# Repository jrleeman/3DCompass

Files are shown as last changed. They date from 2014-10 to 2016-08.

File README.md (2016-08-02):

# 3D Compass

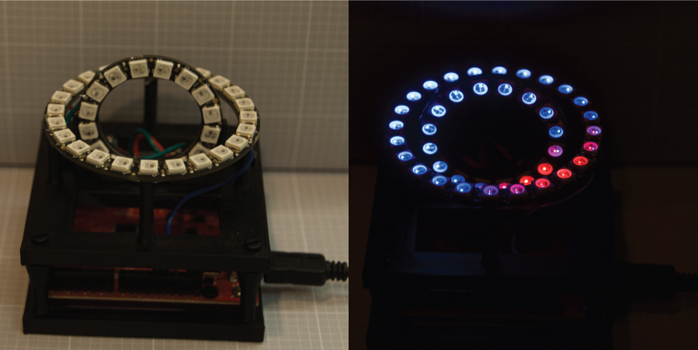
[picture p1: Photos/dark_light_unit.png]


## Bill of Materials
- (1) [Arduino UNO (I used a Red board from SparkFun)](https://www.sparkfun.com/products/12757) $19.95/ea
- (1) [NeoPixel Ring - 16 Element](http://www.adafruit.com/products/1463) $9.95/ea
- (1) [NeoPixil Ring - 24 Element](http://www.adafruit.com/products/1586) $19.95/ea
- (1) [1000uF Capacitor - 6.3V or higher](https://www.sparkfun.com/products/8982) $0.35/ea
- (1) [HMC5883L Magnetometer](http://www.adafruit.com/products/1746) $9.95/ea
- (10) [Brass Heat-Set Insert 4-40](http://www.mcmaster.com/#93365a122/=ub3kod) $11.48/pk. 100
- 0.1" Header Pins
- Hook-up wire (solid)
- 300-500 Ohm Resistor (1/8 watt)
- Nylon 4-40 Screws (1/2 - 1" length)

## Tools Required
- Hobby Knife
- Drill
- Drill Bit 7/64"
- Soldering Iron/Solder
- Flat-head screwdriver
- Hot Glue Gun/Glue
- USB mini cable

## Mechanical Assembly Instructions

### 3D Printing Brackets
- Print 1 top and 1 bottom bracket. 60% infill and a raft are recommended.
- Using a soldering iron, insert the heat-set thread inserts. Eight in
bottom plate, 4 in riser posts, 4 in Arduino mounts. Two in top plate for
magnetometer mounts. [Demonstration Video](http://youtu.be/NXAhOEn8nXQ)

### Assemble Top Plate
- Attach the magnetometer with 4-40 nylon screws. Shear the excess length flush
with the bottom of the plate using a hobby knife. Be careful to not break
the superstructure on the printed part.
- Place the capacitor into the cut-out and secure with a drop of hot glue.
- Solder ~5 cm of wire onto the data in line on the 16-element ring.
- Place the 16-element NeoPixel ring into the vertical ring holder. Thread the
data-in line through the hole in the bracket. This ensures that data-in, V+,
and GND are all accessable. Secure with a drop of hot-glue.
- Place the 24-element NeoPixel ring onto the riser posts. Line up the data-out
pad to be near the data-in line on the smaller ring. The LED should be directly
above the mounting post. Secure with hot-glue on each post.

### Assemble Bottom Plate
- Secure the Arduino RedBoard to the base plate with 4-40 nylon screws. Shear
the excess length flush with the bottom of the plate using a hobby knife.

### Attaching the Plates
- Using the 4-40 nylon screws, attach the top and bottom plates. Shear
the excess length flush with the bottom of the plate using a hobby knife. You
may prefer to do the wiring with the screws out for easy access, but it
shouldn't be too much of a problem.

## Wiring Instructions
* See photos on how to make this easier with header.
- Trim and solder the data-in wire on the vertical ring to the data-out pad
on the 24-element ring.
- Connect the data-in pad on the 24-element horizontal ring to pin 13 on the
Arduino. The resistor goes in-line here as well. You can use 0.1" header to make this easier to assemble and troubleshoot.
- Connect a ground pad from the 24-element horizontal ring to a ground pad
on the 16-element vertical ring.
- Connect the second ground pad on the 16-element vertical ring to the ground
size of the capacitor (marked with -- on the case).
- Connect the ground side of the capacitor to GND on the Arduino. Header can
make this easier.
- Connect the power pads of both rings to the positive side of the capacitor.
- Connect the positive side of the capacitor to +5VDC on the Arduino.
- Connect the GND, SDA, and SCL pins of the magnetometer to GND, SDA, and SCL
on the Arduino.
- Connect the power pin of the magnetometer to the +3.3VDC pin on the Arduino.

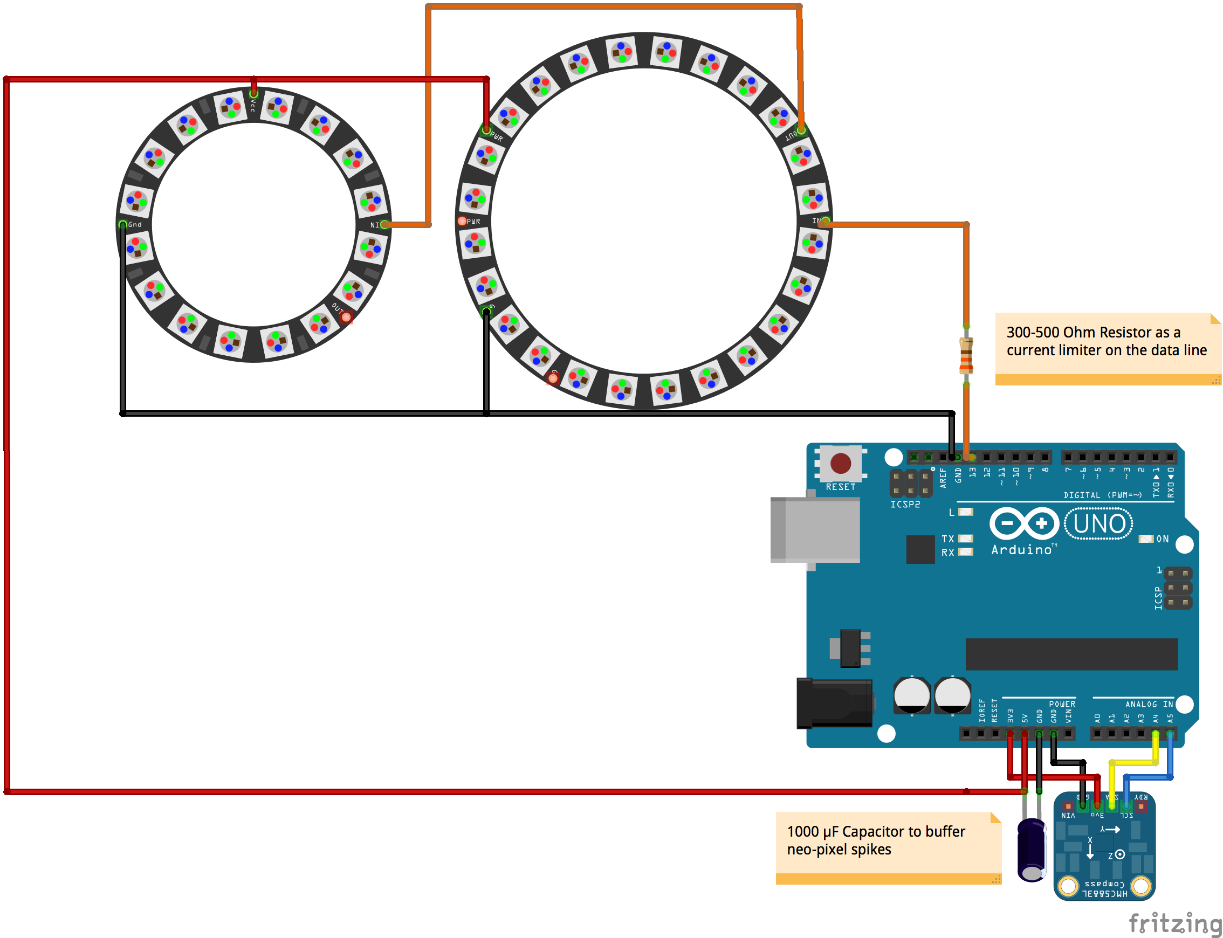
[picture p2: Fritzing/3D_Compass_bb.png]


## Programming
- Install the [NeoPixel](https://github.com/adafruit/Adafruit_NeoPixel),
[Adafruit Sensor](https://github.com/adafruit/Adafruit_Sensor), and
[Magnetometer](https://github.com/adafruit/Adafruit_HMC5883_Unified) libraries.
For help, see the [library tutorial.](https://learn.adafruit.com/adafruit-all-about-arduino-libraries-install-use)
- Connect the Arduino to your computer and upload the code in the Arduino/Vector_Display directory (see the [Arduino guide](http://arduino.cc/en/Guide/HomePage)) if you need help uploading programs to the Arduino.
- Play with parameters such as brightness and grading to create your own display!
- The `#define DECLINATION` directive adjusts the compass headings for your current location.  You can look up this value on the [CIRES World Magnetic Map](http://geomag.org/models/wmm-declination.html), but you need to convert the DMS to radians.

## Activity Ideas
You can learn a lot from your new compass/magnetometer! In addition to learning about the
electronics and hardware, you can learn about magnetic fields and the Earth's geodynamo. Below are a few links to get you started and some ideas. Please contribute any experiments or activities that you develop!

- Learn how magnetometer calibration works ([Freescale App Note](http://www.freescale.com/files/sensors/doc/app_note/AN4246.pdf))
- Measure the diurnal variation in [Earth's magnetic field](http://geophysics.ou.edu/solid_earth/notes/mag_earth/earth.htm)
- See how good of a [metal detector](http://en.wikipedia.org/wiki/Metal_detector) you built
- Detect the movement of metal objects like a desk drawer

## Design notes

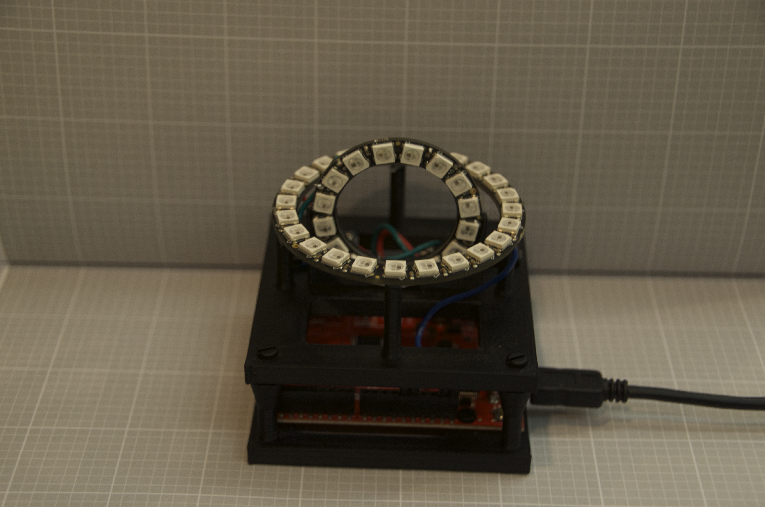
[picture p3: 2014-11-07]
Photos/unit_overview_2.jpg

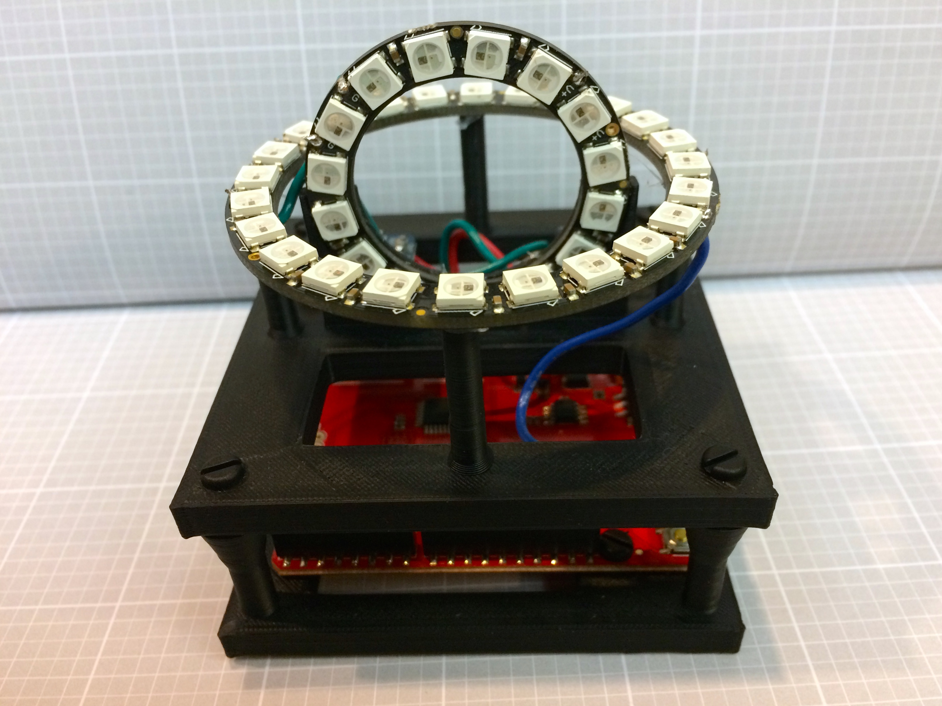
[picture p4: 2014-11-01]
Photos/unit_overview.jpg

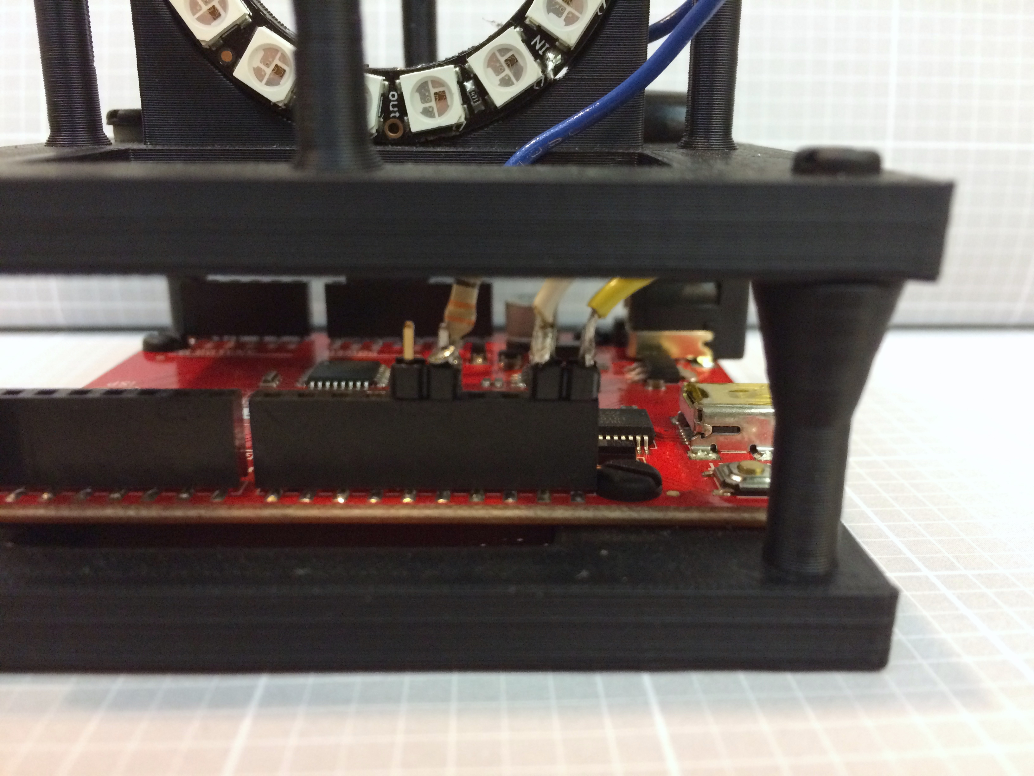
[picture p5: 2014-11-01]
Photos/side_b_detail.jpg

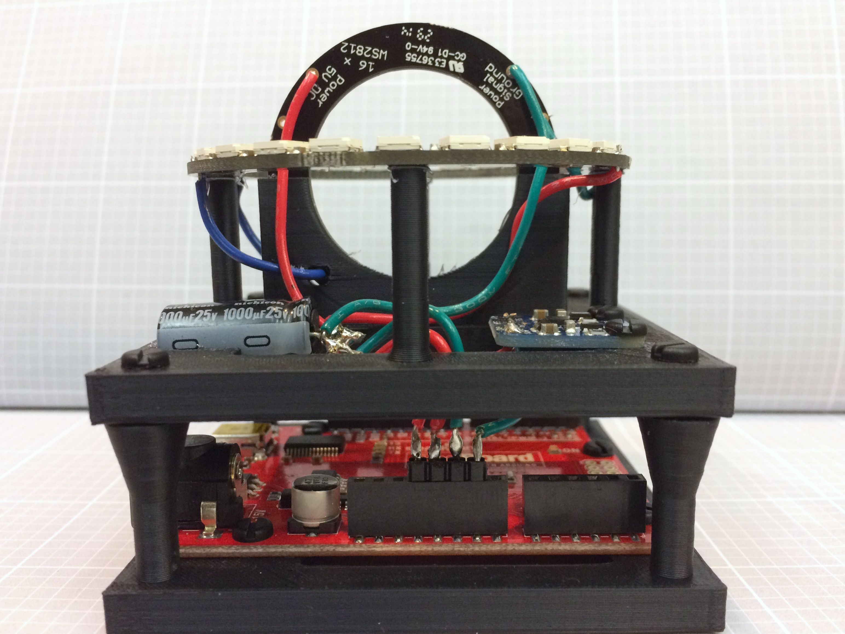
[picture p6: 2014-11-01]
Photos/side_a.jpg

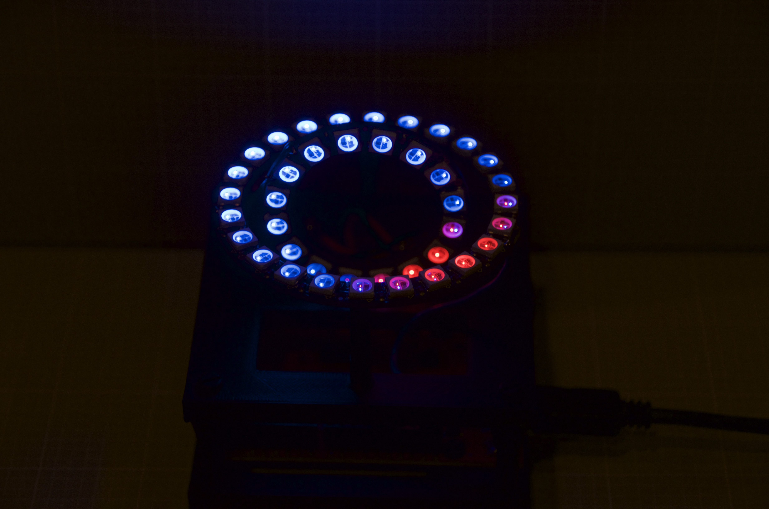
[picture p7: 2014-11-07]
Photos/unit_lighted.jpg

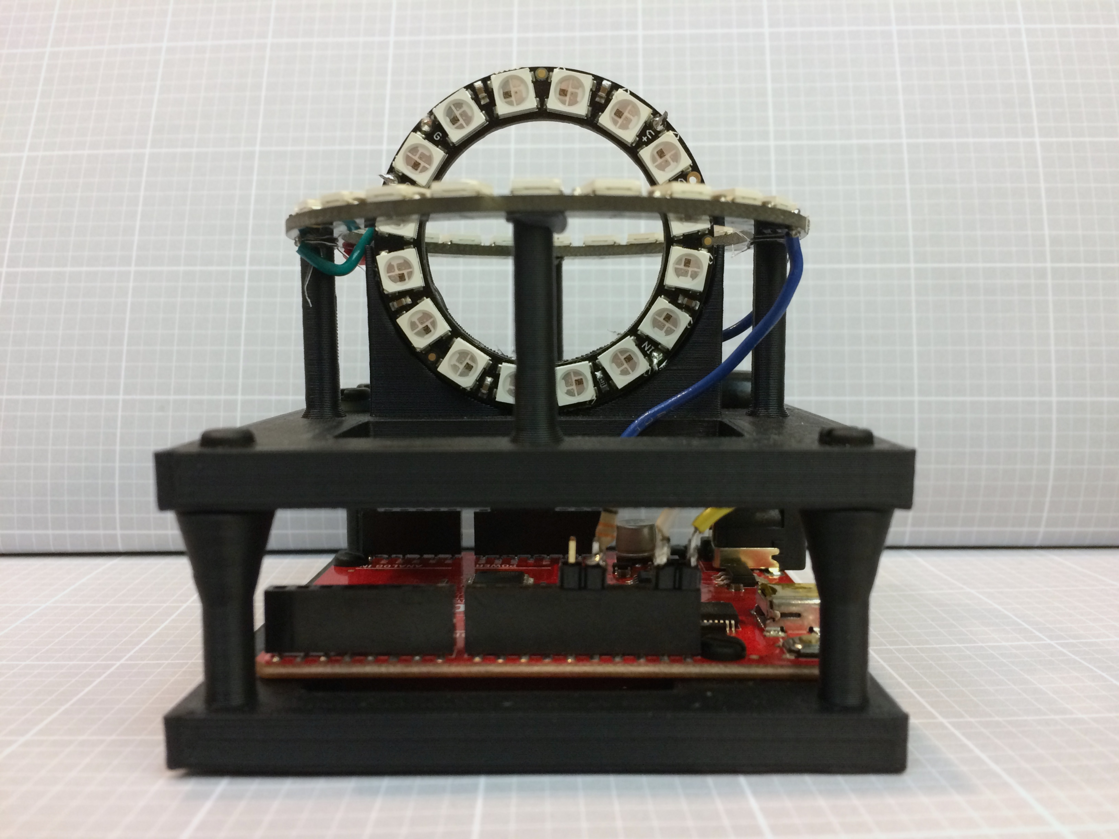
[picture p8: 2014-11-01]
Photos/side_b.jpg

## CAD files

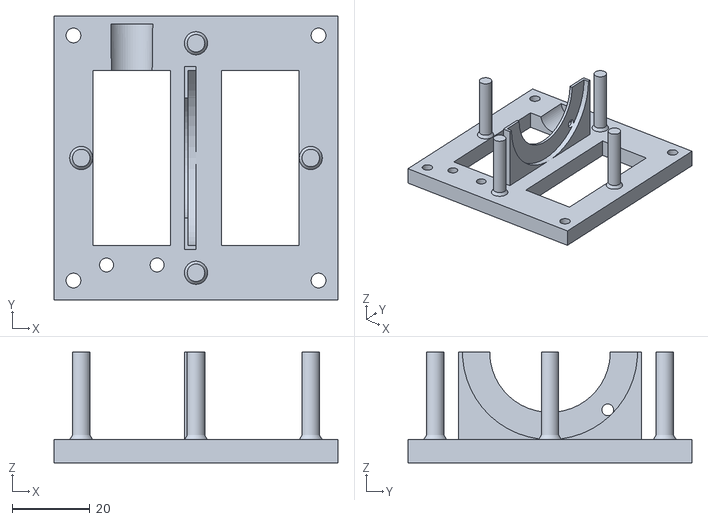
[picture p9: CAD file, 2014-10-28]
Printed_Parts/top_plate.stl
73.0 x 73.0 x 28.5

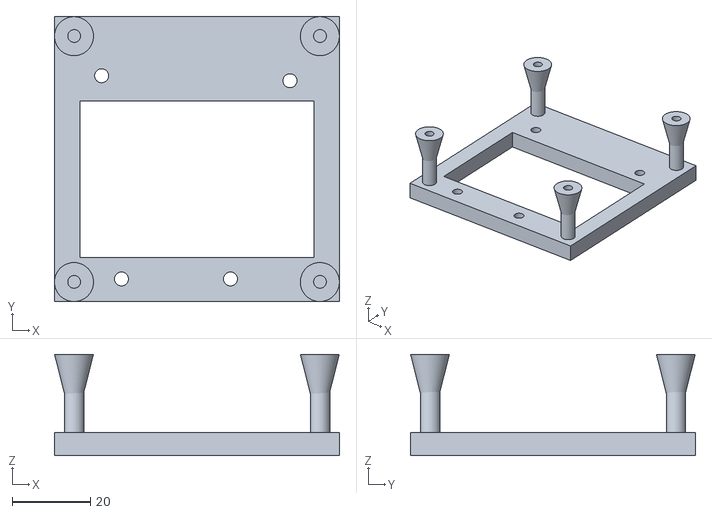
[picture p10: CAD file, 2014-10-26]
Printed_Parts/bottom_plate.stl
73.0 x 73.0 x 26.0

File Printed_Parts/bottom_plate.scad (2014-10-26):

// Resolution
$fn=50;

// Base
width = 73;
thickness = 6;
length = 73;
inside_thickness = 35;

x_offset = 9.5;
y_offset = 3.2;
hole_offset = 5;

cutout_width = 60;
cutout_height = 40;

post_size = 5;
post_height = 20;

4_40_radius = 1.64;
4_40_depth = 6.6;

difference(){
cube([width,length,thickness]);

translate([width/2.-cutout_width/2.,length/2.-cutout_height/2. - y_offset -2,0])cube([cutout_width,cutout_height,10]);

// Holes for Arduino mount threaded inserts
translate([3*2.54+x_offset,1*2.54+y_offset,0])cylinder(7,3.5814/2,3.5814/2);
translate([14*2.54+x_offset,1*2.54+y_offset,0])cylinder(7,3.5814/2,3.5814/2);
translate([1*2.54+x_offset,21.5*2.54+y_offset,0])cylinder(7,3.5814/2,3.5814/2);
translate([20*2.54+x_offset,21*2.54+y_offset,0])cylinder(7,3.5814/2,3.5814/2);
}

//Corner posts
difference(){
union(){
translate([hole_offset,hole_offset,thickness])
cylinder(post_height,post_size/2.,post_size/2.);

translate([hole_offset-post_size/2.+4_40_radius*1.5,hole_offset-post_size/2.+4_40_radius*1.5,thickness+post_height/2])
cylinder(post_height/2,4_40_radius*1.5,post_size);
}

// Holes for bracket mount 4-40 through hole
translate([hole_offset,hole_offset,thickness+post_height-4_40_depth])
cylinder(4_40_depth+1,4_40_radius,4_40_radius);
}

difference(){
union(){
translate([hole_offset,length-hole_offset,thickness])
cylinder(post_height,post_size/2.,post_size/2.);

translate([hole_offset-post_size/2.+4_40_radius*1.5,length-hole_offset-post_size/2.+4_40_radius*1.5,thickness+post_height/2])
cylinder(post_height/2,4_40_radius*1.5,post_size);
}

translate([hole_offset,length-hole_offset,thickness+post_height-4_40_depth])
cylinder(4_40_depth+1,4_40_radius,4_40_radius);

}

difference(){
union(){
translate([width-hole_offset,length-hole_offset,thickness])
cylinder(post_height,post_size/2.,post_size/2.);

translate([width-hole_offset-post_size/2.+4_40_radius*1.5,length-hole_offset-post_size/2.+4_40_radius*1.5,thickness+post_height/2])
cylinder(post_height/2,4_40_radius*1.5,post_size);
}

translate([width-hole_offset,length-hole_offset,thickness+post_height-4_40_depth])
cylinder(4_40_depth+1,4_40_radius,4_40_radius);

}

difference(){
union(){
translate([width-hole_offset,hole_offset,thickness])
cylinder(post_height,post_size/2.,post_size/2.);

translate([width-hole_offset-post_size/2.+4_40_radius*1.5,hole_offset-post_size/2.+4_40_radius*1.5,thickness+post_height/2])
cylinder(post_height/2,4_40_radius*1.5,post_size);
}

translate([width-hole_offset,hole_offset,thickness+post_height-4_40_depth])
cylinder(4_40_depth+1,4_40_radius,4_40_radius);

}

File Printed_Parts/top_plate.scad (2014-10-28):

// Resolution
$fn=50;

// Base
width = 73;
thickness = 6;
length = 73;
inside_thickness = 35;

x_offset = 7.5;
y_offset = 5.7;
hole_offset = 5;

mag_x_pos = 13.5;
mag_y_pos = 9;
mag_spacing = 13;

cutout_width = 20;
cutout_height = 45;

difference(){
cube([width,length,thickness]);

translate([10,length/2.-cutout_height/2.,0])cube([cutout_width,cutout_height,10]);
translate([width-10-cutout_width,length/2.-cutout_height/2.,0])cube([cutout_width,cutout_height,10]);

// Holes for magnetometer mount threaded inserts
translate([mag_x_pos,mag_y_pos,0])cylinder(7,3.5814/2,3.5814/2);
translate([mag_x_pos+mag_spacing,mag_y_pos,0])cylinder(7,3.5814/2,3.5814/2);

// Holes for bracket mount 4-40 through hole
translate([hole_offset,hole_offset,0])cylinder(7,1.9,1.9);
translate([hole_offset,length-hole_offset,0])cylinder(7,1.9,1.9);
translate([width-hole_offset,hole_offset,0])cylinder(7,1.9,1.9);
translate([width-hole_offset,length-hole_offset,0])cylinder(7,1.9,1.9);

// Cutout for capacitor
translate([10+cutout_width/2.,length/2.+cutout_height/2.+12,thickness+1])
rotate([90,0,0])
cylinder(20.,5.5,5.25);

}

// Support post sizes
post_radius = 4.5/2.;
post_height = 45/2.;

fillet_height = 0.05;
fillet_radius = 1.32;

// Neopixil Ring Sizes
largeRing_cc = 59;
smallRing_OD = 45;
smallRing_ID = 31;

// Horizontal Ring Support Posts
translate([width/2.-largeRing_cc/2.,length/2.,thickness])
cylinder(post_height,post_radius,post_radius);
translate([width/2.-largeRing_cc/2.,length/2.,thickness])
cylinder(post_height*fillet_height,post_radius*fillet_radius,post_radius);

translate([width/2.+largeRing_cc/2.,length/2.,thickness])
cylinder(post_height,post_radius,post_radius);
translate([width/2.+largeRing_cc/2.,length/2.,thickness])
cylinder(post_height*fillet_height,post_radius*fillet_radius,post_radius);

translate([width/2.,length/2.-largeRing_cc/2.,thickness])
cylinder(post_height,post_radius,post_radius);
translate([width/2.,length/2.-largeRing_cc/2.,thickness])
cylinder(post_height*fillet_height,post_radius*fillet_radius,post_radius);

translate([width/2.,length/2.+largeRing_cc/2.,thickness])
cylinder(post_height,post_radius,post_radius);
translate([width/2.,length/2.+largeRing_cc/2.,thickness])
cylinder(post_height*fillet_height,post_radius*fillet_radius,post_radius);

// Supports for vertical ring

translate([width/2.,length/2,smallRing_OD/2.+thickness])
rotate([0,270,0])

difference(){
// Support block for ring
translate([(smallRing_OD+2)/-2.,(smallRing_OD+2)/-2.,0]) cube([(smallRing_OD+2)/2.,(smallRing_OD+2),3]);

// Rectangle to cut shape to half circle
translate([0,(smallRing_OD+10)/-2.,0]) cube([(smallRing_OD+10),(smallRing_OD+10),4]);

// Recessed disc to hold ring
cylinder(2,smallRing_OD/2.,smallRing_OD/2.);

// Cutout hole in center
cylinder(4,smallRing_ID/2.,smallRing_ID/2.);

// Wire hole cutout
translate([-21*0.707,21*0.707,0])cylinder(4,1.5,1.5);
}

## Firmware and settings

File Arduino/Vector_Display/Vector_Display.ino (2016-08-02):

/*
  Vector_Display.ino

  Displays the orientation of the magnetic vector on two neo-pixel rings.
  North and the inclination are marked by red, faded to blue for contrast.

  Created: 10/30/14
  Author: John R. Leeman
  www.johnrleeman.com
  www.github.com/jrleeman

  Modified: 7/20/16
  Author: Ryan Claussen
  wwww.github.com/rtclauss
*/


#include <Adafruit_NeoPixel.h>
#include <Wire.h>
#include <Adafruit_Sensor.h>
#include <Adafruit_HMC5883_U.h>

#define PIXELPIN 13 // Pin on the Arduino that the Neopixel chain is connected to
#define NUMAZ 24  // Number of pixels on the azimuth ring
#define NUMINC 16 // Number of pixels on the inclination ring
#define INCANGLE 259 //Angle that pixel "zero" is at on inclination ring (nearest degree)
#define AZANGLE 285 //Angle that pixel zero is at on azimuth ring (nearest degree)
#define STREAMDECIMATE 25 // Number of reads to write out to the serial stream
#define BRIGHTNESS 1 // Increase or decrease for brighter/dimmer colors

// Declination in radians, go to http://geomag.org/models/wmm-declination.html
// to find your declination, then convert it to decimal degrees. To convert 
// DMS to decimal degrees add minutes/60 and seconds/3600 to the whole degrees.
// Multiply that angle by 2*pi/180 to convert to radians from degrees. 
// West is negative, East is positive
// This is the declination for Brookings, SD in the 2015-2020 WMM.
#define DECLINATION 0.05

// Floats to store heading and inclination
float heading;
float inclination;

// Counter to update serial output more slowly
int count = 0;

// Setup neopixel and magnetometer
Adafruit_HMC5883_Unified mag = Adafruit_HMC5883_Unified(12345);
Adafruit_NeoPixel strip = Adafruit_NeoPixel(NUMAZ + NUMINC, PIXELPIN, NEO_GRB + NEO_KHZ800);

void setup() {
  // Start strip and make all pixels dark
  strip.begin();
  strip.show();

  // Start the serial port to stream data back
  Serial.begin(115200);
  Serial.println("3D Compass Demonstration");
  Serial.println("");
  Serial.println("X,Y,Z,Heading,Inclination");
  Serial.println("nT,nT,nT,deg,deg");

  // Start the magnetometer
  if(!mag.begin())
  {
    Serial.println("No Magnetic Sensor Detected...");
    while(1);
  }

}

void loop() {
  // Read the sensor
  sensors_event_t event;
  mag.getEvent(&event);

  // Calculate the heading and inclination from the data and convert to degrees
  heading = 180/M_PI * calcHeading(event.magnetic.x,event.magnetic.y,event.magnetic.z);
  inclination = 180/M_PI * calcInclination(event.magnetic.x,event.magnetic.y,event.magnetic.z);

  // Every #STREAMDECIMATE reads, display data
  if (count%STREAMDECIMATE == 0){
    Serial.print(event.magnetic.x); Serial.print(",");
    Serial.print(event.magnetic.y); Serial.print(",");
    Serial.print(event.magnetic.z); Serial.print(",");
    Serial.print(heading); Serial.print(",");
    Serial.println(inclination);
    count = 0; //prevent overflow of int
  }

  // Plot the Azimuth
  plotAzimuth(360 - heading);

  // Plot the Inclination
  plotInclination(inclination,360-heading);

  count += 1;
}

void plotAzimuth(int angle){
  int red;
  int blue;
  int pixDeg;

   for(int i=0;i<NUMAZ;i++){

    // Calculate angle that pixel is at and make sure it is
    // in 0-360
    pixDeg = AZANGLE + i*15;

    if (pixDeg > 360){
      pixDeg -= 360;
    }

    // Color based on difference of given angle and pixel angle
    int diff = abs(pixDeg - angle);

    // If the difference is over 180, we'll loop back to lower values of
    // difference since this is a ring
    if (diff>180){
      diff = abs(360 - diff);
    }

    // Do red coloring, increase the value for a larger red area, decrease
    // for less red. If negative, set to zero
    red = 60 - diff;
    if (red<0){
      red = 0;
    }

    // Do difference 180 from heading for south (blue) coloring and make
    // sure it is in range
    diff = abs(pixDeg - angle - 180);

    if (diff>180){
      diff = abs(360 - diff);
    }

    // Do blue coloring, increase the value for a larger blue area, decrease
    // for less blue. If negative, set to zero
    blue = 170 -diff;
    if (blue<0){
      blue = 0;
    }

    // Set pixel color brightnesses
    red = red*BRIGHTNESS;
    blue = blue*BRIGHTNESS/5;

    // Make sure neither is over 255
    if (red > 255){
      red = 255;
    }

    if (blue > 255){
      blue = 255;
    }
    //Actually set the color on the NeoPixel ring
    strip.setPixelColor(i,red,0,blue);
  }
  //Refresh the NeoPixel displays
  strip.show();
}

void plotInclination(float angle, float heading){
  int red;
  int blue;
  int pixDeg;

  // Check if negative, and if so put at correct positive angle
  if (angle < 0){
    angle += 360;
  }

  // Do azimuth switching if necessary
  if (heading > 180){
    angle = 180 - angle ;
  }

  // Make sure we are under 360
  while (angle > 360){
    angle -= 360;
  }

  // Make sure we are over zero
  if (angle < 0){
    angle += 360;
  }

  for(int i=0;i<NUMINC;i++){
    pixDeg = INCANGLE - i*22.5;

    if (pixDeg < 0){
      pixDeg += 360;
    }

    // Color based on difference of given angle and pixel angle
    int diff = abs(pixDeg - angle);

    // If the difference is over 180, we'll loop back to lower values of
    // difference since this is a ring
    if (diff>180){
      diff = abs(360 - diff);
    }

    // Do red coloring, increase the value for a larger red area, decrease
    // for less red. If negative, set to zero
    red = 60 - diff;
    if (red<0){
      red = 0;
    }

    // Do difference 180 from heading for south (blue) coloring and make
    // sure it is in range
    diff = abs(pixDeg - angle - 180);

    if (diff>180){
      diff = abs(360 - diff);
    }

    // Do blue coloring, increase the value for a larger blue area, decrease
    // for less blue. If negative, set to zero
    blue = 170 -diff;
    if (blue<0){
      blue = 0;
    }

    // Set pixel color brightness
    red = red*BRIGHTNESS;
    blue = blue*BRIGHTNESS/5;

    // Make sure neither is over 255
    if (red > 255){
      red = 255;
    }

    if (blue > 255){
      blue = 255;
    }
    //Actually set the color on the NeoPixel ring
    strip.setPixelColor(i+NUMAZ,red,0,blue);
  }
  //Refresh the NeoPixel displays
  strip.show();
}



float calcInclination(float x, float y, float z)
{
  /* Given x,y,z componets of a field, return the
     inclination angle w.r.t horizontal in radians. */
  return atan2(z,sqrt(x*x + y*y));
}

float calcHeading(float x, float y, float z)
{
  /* Given x,y,z componets of a field, return the
     heading angle w.r.t "north". This assumes that
     x is "east", y is "north", and z is "up".*/
  float theta;
  theta = atan2(y, x);
  theta -= DECLINATION;
  theta -= 0.5 * PI;

  if (theta < 0){
    theta += 2*PI;
  }

  if (theta > 2*PI){
    theta -= 2*PI;
  }

  return theta;
}

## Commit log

2014-10-25 Move center cutouts to true center on top plate
    [top_plate.scad]
2014-10-25 Move arduino to be flush with edge, beef up risers, and adjust cutout
    [bottom_plate.scad]
2014-10-25 Add capacitor cutout for neopixil power cap
    [top_plate.scad]
2014-10-25 Add fillet to riser posts on top bracket to increase durability
    [top_plate.scad]
2014-10-25 Add hole for wire in vertical neopixil ring
    [top_plate.scad]
2014-10-25 Update stl files to most recent scad
    [bottom_plate.stl, top_plate.stl]
2014-10-25 Add BOM and begin assembly instructions
2014-10-26 Modify the melt in holes.
    Change the square posts to round and add taper.
    [bottom_plate.scad, bottom_plate.stl]
2014-10-28 Modify top plate to improve fit.
    - Increase buffer on bottom of capacitor cutout to prevent see
    see through prints
    - Increase through hole 4-40 clearance
    [top_plate.scad, top_plate.stl]
2014-10-28 Correct pin numbers in Arduino sketch
    [Arduino.ino]
2014-10-31 Add more assembly/wiring instructions
2014-11-01 Add Photos of Prototype Unit.
2014-11-02 Reduce serial data rate and remove debug
    Add counter to allow display to update much faster than the
    serial data rate so that students aren't overwhelmed with
    hundreds of readings per second. Also remove debug serial prints
    from the azimuthPlot function.
2014-12-24 Add fritzing diagram
    [3D_Compass.fzz]
2014-12-24 Update with wiring diagram
2016-08-02 Update magnetic inclination
    Updated magnetic inclination to Brookings, SD and changed calculation algorithm to match best practices.
2016-08-02 Fix some spelling errors
    [Vector_Display.ino]
2016-08-02 Add schematic
